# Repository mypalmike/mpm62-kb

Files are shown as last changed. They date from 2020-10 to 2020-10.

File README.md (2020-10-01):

# mpm62-kb
Schematics etc for split 62-key 60% keyboard.

Left side uses an arduino pro micro with left-side exit. Right side uses expander. Simple 4-pin connector carries i2c.

## Status

Currently in early stages.

* 2020-09-04 - Probably not final, but first potentially viable schematic.
* 2020-09-06 - Right-side (more complex) PCB routing complete.
* 2020-09-30 - (branch) Both sides updated for throughhole solder and expander to simplify wiring.

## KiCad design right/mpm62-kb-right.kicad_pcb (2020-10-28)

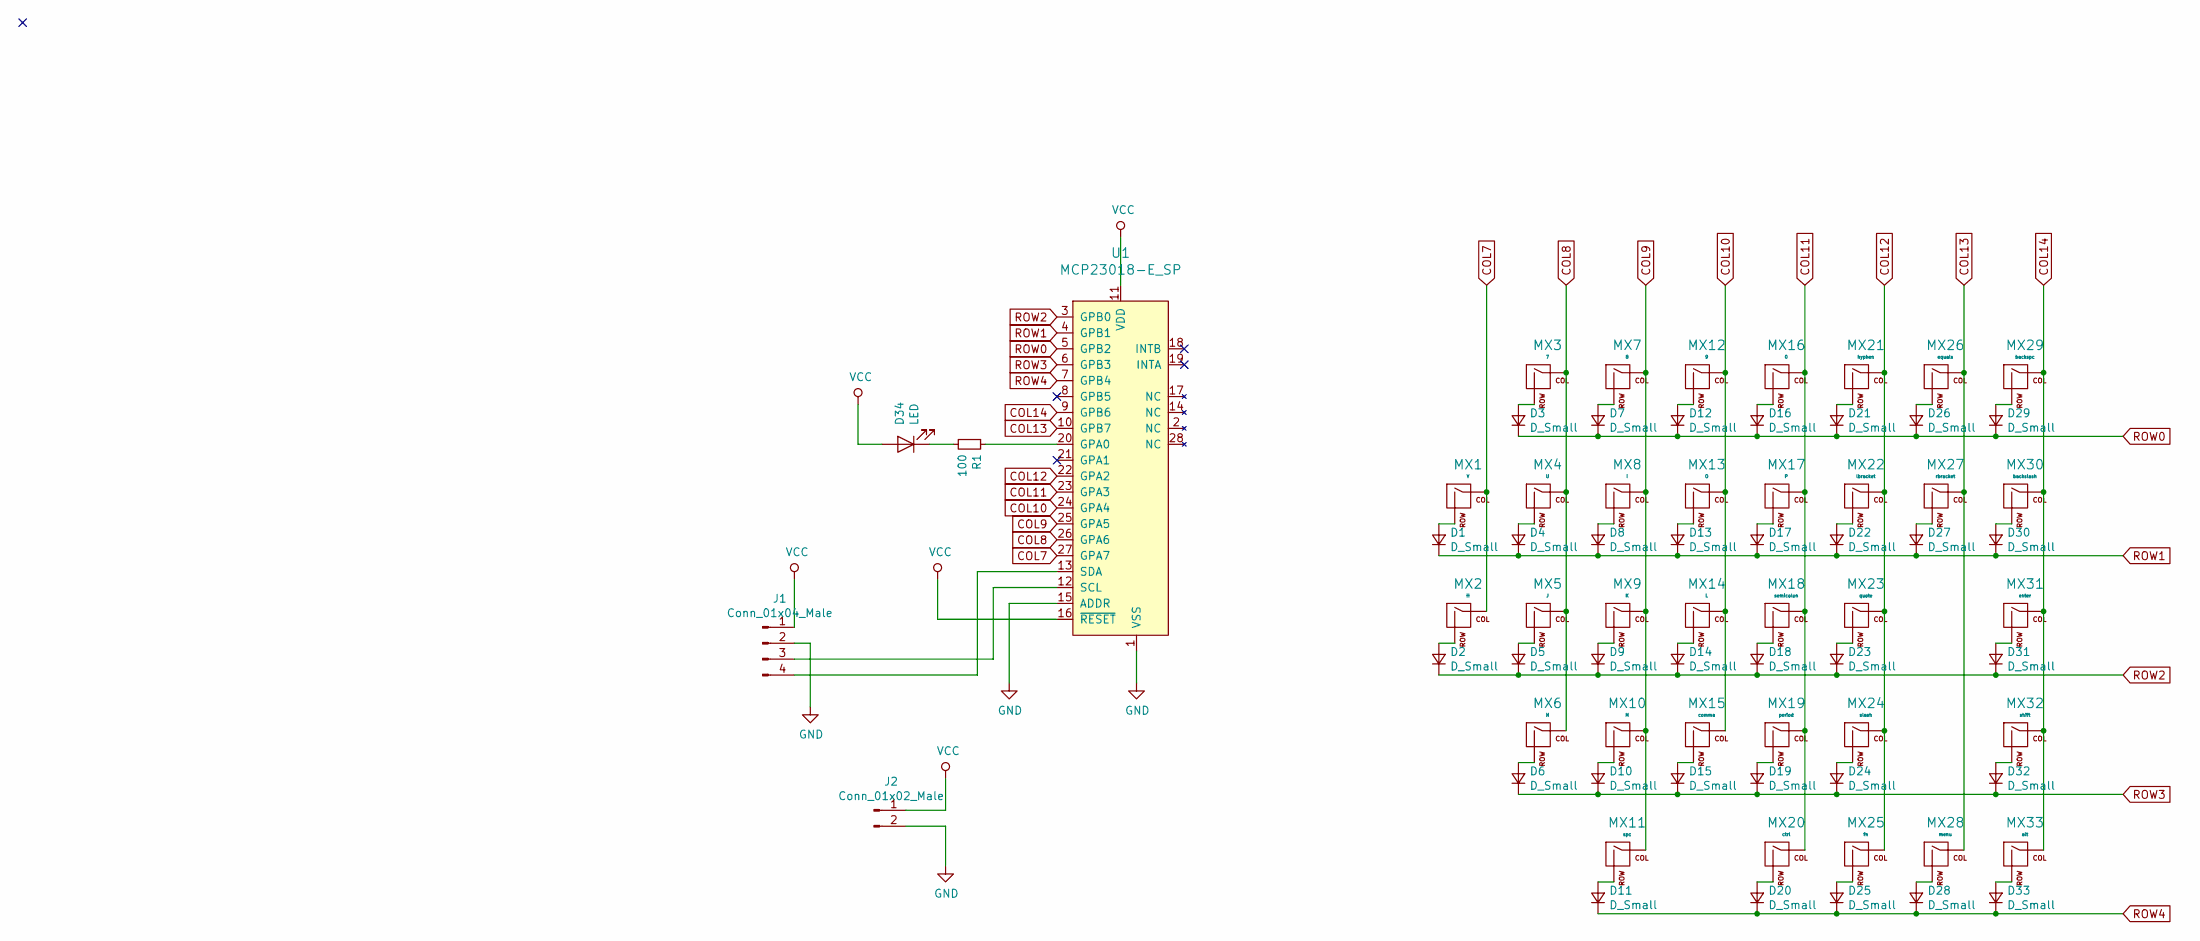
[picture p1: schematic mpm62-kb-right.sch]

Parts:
D1, D2, D3, D4, D5, D6, D7, D8, D9, D10, D11, D12, D13, D14, D15, D16, D17, D18, D19, D20, D21, D22, D23, D24, D25, D26, D27, D28, D29, D30, D31, D32, D33: D_Small; D_DO-35_SOD27_P7.62mm_Horizontal
D34: LED; LED_D3.0mm
J1: Conn_01x04_Male; PinHeader_1x04_P2.54mm_Vertical
J2: Conn_01x02_Male; PinHeader_1x02_P2.54mm_Vertical
MX1: Y; MX-1U-NoLED
MX2: H; MX-1U-NoLED
MX3: 7; MX-1U-NoLED
MX4: U; MX-1U-NoLED
MX5: J; MX-1U-NoLED
MX6: N; MX-1U-NoLED
MX7: 8; MX-1U-NoLED
MX8: I; MX-1U-NoLED
MX9: K; MX-1U-NoLED
MX10: M; MX-1U-NoLED
MX11: spc; MX-3U-ReversedStabilizers-NoLED
MX12: 9; MX-1U-NoLED
MX13: O; MX-1U-NoLED
MX14: L; MX-1U-NoLED
MX15: comma; MX-1U-NoLED
MX16: 0; MX-1U-NoLED
MX17: P; MX-1U-NoLED
MX18: semicolon; MX-1U-NoLED
MX19: period; MX-1U-NoLED
MX20: ctrl; MX-1.25U-NoLED
MX21: hyphen; MX-1U-NoLED
MX22: lbracket; MX-1U-NoLED
MX23: quote; MX-1U-NoLED
MX24: slash; MX-1U-NoLED
MX25: fn; MX-1.25U-NoLED
MX26: equals; MX-1U-NoLED
MX27: rbracket; MX-1U-NoLED
MX28: menu; MX-1.25U-NoLED
MX29: backspc; MX-2U-NoLED
MX30: backslash; MX-1.5U-NoLED
MX31: enter; MX-2.25U-NoLED
MX32: shift; MX-2.75U-NoLED
MX33: alt; MX-1.25U-NoLED
R1: 100; R_Axial_DIN0207_L6.3mm_D2.5mm_P7.62mm_Horizontal
U1: MCP23018-E_SP; DIP-28_W7.62mm; MPN MCP23018-E/SP; Digi-Key_PN MCP23018-E/SP-ND

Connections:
COL7: MX1.1 (COL), MX2.1 (COL), U1.27 (GPA7)
COL8: MX3.1 (COL), MX4.1 (COL), MX5.1 (COL), MX6.1 (COL), U1.26 (GPA6)
COL9: MX7.1 (COL), MX8.1 (COL), MX9.1 (COL), MX10.1 (COL), MX11.1 (COL), U1.25 (GPA5)
COL10: MX12.1 (COL), MX13.1 (COL), MX14.1 (COL), MX15.1 (COL), U1.24 (GPA4)
COL11: MX16.1 (COL), MX17.1 (COL), MX18.1 (COL), MX19.1 (COL), MX20.1 (COL), U1.23 (GPA3)
COL12: MX21.1 (COL), MX22.1 (COL), MX23.1 (COL), MX24.1 (COL), MX25.1 (COL), U1.22 (GPA2)
COL13: MX26.1 (COL), MX27.1 (COL), MX28.1 (COL), U1.10 (GPB7)
COL14: MX29.1 (COL), MX30.1 (COL), MX31.1 (COL), MX32.1 (COL), MX33.1 (COL), U1.9 (GPB6)
GND: J1.2, J2.2, U1.1 (VSS), U1.15 (ADDR)
unnamed: D1.2 (A), MX1.2 (ROW)
unnamed: D2.2 (A), MX2.2 (ROW)
unnamed: D3.2 (A), MX3.2 (ROW)
unnamed: D4.2 (A), MX4.2 (ROW)
unnamed: D5.2 (A), MX5.2 (ROW)
unnamed: D6.2 (A), MX6.2 (ROW)
unnamed: D7.2 (A), MX7.2 (ROW)
unnamed: D8.2 (A), MX8.2 (ROW)
unnamed: D9.2 (A), MX9.2 (ROW)
unnamed: D10.2 (A), MX10.2 (ROW)
unnamed: D11.2 (A), MX11.2 (ROW)
unnamed: D12.2 (A), MX12.2 (ROW)
unnamed: D13.2 (A), MX13.2 (ROW)
unnamed: D14.2 (A), MX14.2 (ROW)
unnamed: D15.2 (A), MX15.2 (ROW)
unnamed: D16.2 (A), MX16.2 (ROW)
unnamed: D17.2 (A), MX17.2 (ROW)
unnamed: D18.2 (A), MX18.2 (ROW)
unnamed: D19.2 (A), MX19.2 (ROW)
unnamed: D20.2 (A), MX20.2 (ROW)
unnamed: D21.2 (A), MX21.2 (ROW)
unnamed: D22.2 (A), MX22.2 (ROW)
unnamed: D23.2 (A), MX23.2 (ROW)
unnamed: D24.2 (A), MX24.2 (ROW)
unnamed: D25.2 (A), MX25.2 (ROW)
unnamed: D26.2 (A), MX26.2 (ROW)
unnamed: D27.2 (A), MX27.2 (ROW)
unnamed: D28.2 (A), MX28.2 (ROW)
unnamed: D29.2 (A), MX29.2 (ROW)
unnamed: D30.2 (A), MX30.2 (ROW)
unnamed: D31.2 (A), MX31.2 (ROW)
unnamed: D32.2 (A), MX32.2 (ROW)
unnamed: D33.2 (A), MX33.2 (ROW)
unnamed: D34.1 (K), R1.2
unnamed: J1.3, U1.12 (SCL)
unnamed: J1.4, U1.13 (SDA)
unnamed: R1.1, U1.20 (GPA0)
ROW0: D3.1 (K), D7.1 (K), D12.1 (K), D16.1 (K), D21.1 (K), D26.1 (K), D29.1 (K), U1.5 (GPB2)
ROW1: D1.1 (K), D4.1 (K), D8.1 (K), D13.1 (K), D17.1 (K), D22.1 (K), D27.1 (K), D30.1 (K), U1.4 (GPB1)
ROW2: D2.1 (K), D5.1 (K), D9.1 (K), D14.1 (K), D18.1 (K), D23.1 (K), D31.1 (K), U1.3 (GPB0)
ROW3: D6.1 (K), D10.1 (K), D15.1 (K), D19.1 (K), D24.1 (K), D32.1 (K), U1.6 (GPB3)
ROW4: D11.1 (K), D20.1 (K), D25.1 (K), D28.1 (K), D33.1 (K), U1.7 (GPB4)
VCC: D34.2 (A), J1.1, J2.1, U1.11 (VDD), U1.16 (~RESET)

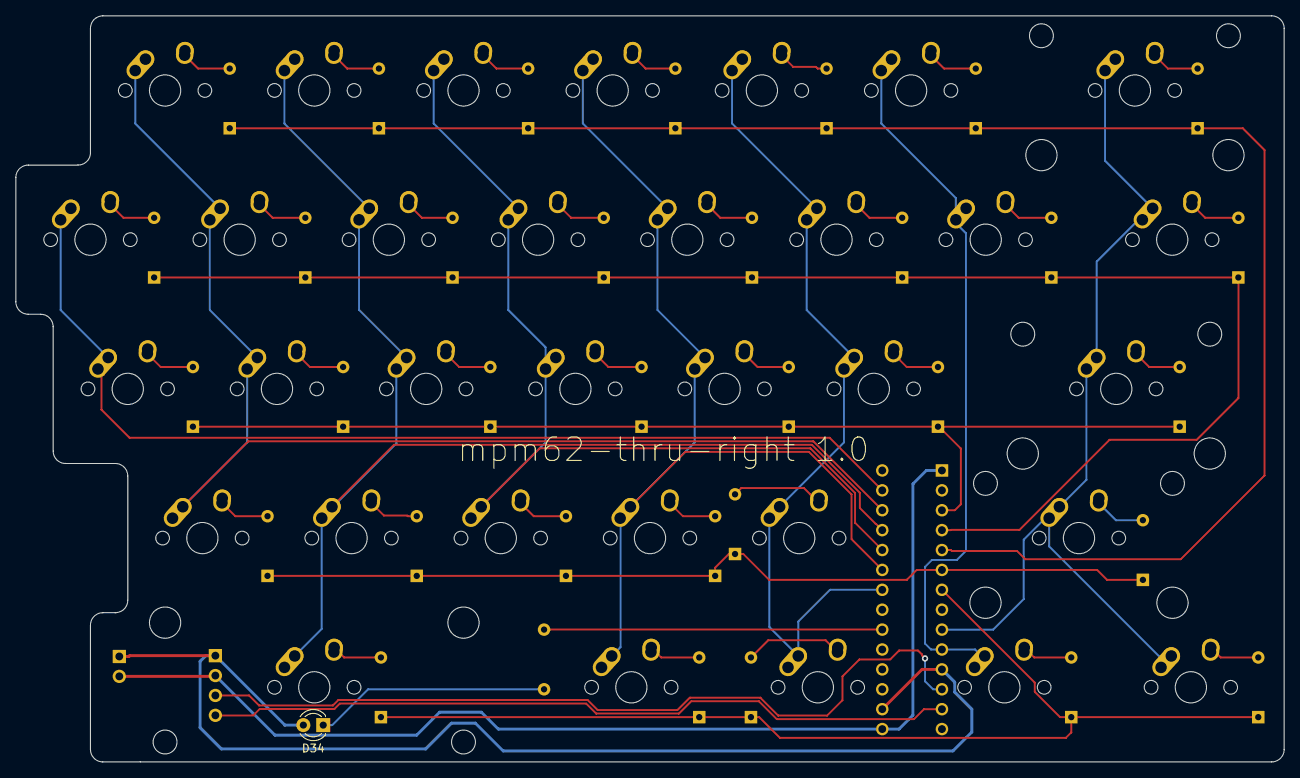
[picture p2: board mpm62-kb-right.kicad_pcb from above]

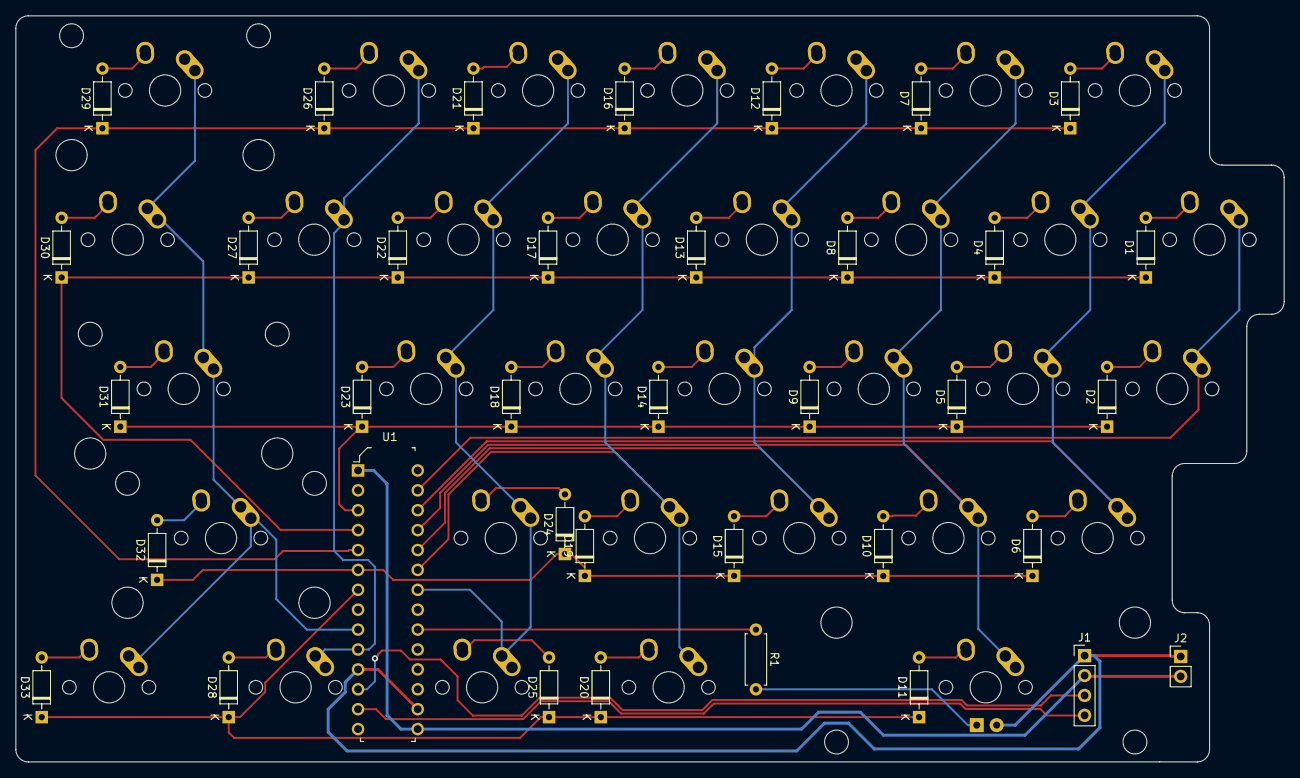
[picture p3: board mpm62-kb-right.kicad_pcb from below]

Board: 2 copper layers, 161.9 x 95.2 mm, 71 parts (37 on the bottom side), 52 nets.

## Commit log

2020-09-01 Initial empty project
    [mpm62-kb-left.kicad_pcb, mpm62-kb-left.sch]
2020-09-01 left schematic first pass
    [mpm62-kb-left.sch]
2020-09-01 Initial project for right
    [mpm62-kb-right.kicad_pcb, mpm62-kb-right.sch]
2020-09-01 Add cache schematic lib for left
2020-09-01 Right MCU and switch layout.
    [mpm62-kb-right.sch]
2020-09-04 complete schematics for both left and right
    [mpm62-kb-left.sch, mpm62-kb-right.sch]
2020-09-06 Add usb connector. Cleaned up crystal in schematic.
    [mpm62-kb-right.sch]
2020-09-06 Annotated components
    [mpm62-kb-right.sch]
2020-09-06 Assigned footprints
    [mpm62-kb-right.sch]
2020-09-06 Right pcb almost done.
    [mpm62-kb-right.kicad_pcb]
2020-09-07 Right pcb complete
    [mpm62-kb-right.kicad_pcb]
2020-09-07 Minor pcb cleanup near crystal.
    [mpm62-kb-right.kicad_pcb]
2020-09-30 Schematic and pre-routed right-side based on mcp23018
    [mpm62-kb-right.kicad_pcb, mpm62-kb-right.sch]
2020-09-30 Fix resistor footprint, clean up layout.
    [mpm62-kb-right.kicad_pcb, mpm62-kb-right.sch]
2020-09-30 Finished right side routing, some simplification, ground fill.
    [mpm62-kb-right.kicad_pcb, mpm62-kb-right.sch]
2020-09-30 Add version text to front silk layer
    [mpm62-kb-right.kicad_pcb]
2020-10-01 left side pcb components in place, not routed.
    [mpm62-kb-left.kicad_pcb, mpm62-kb-left.sch]
2020-10-01 Left side routed.
    [mpm62-kb-left.kicad_pcb, mpm62-kb-left.sch]
2020-10-01 left side ground filled and silk layer label
    [mpm62-kb-left.kicad_pcb]
2020-10-01 Generated gerbers.
    [mpm62-kb-left-B_Cu.gbl, mpm62-kb-left-B_Mask.gbs, mpm62-kb-left-B_SilkS.gbo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]
2020-10-01 Fix some small components in path of stabilizers.
    [mpm62-kb-right.kicad_pcb]
2020-10-01 Generated right side gerber files.
    [mpm62-kb-right-B_Cu.gbl, mpm62-kb-right-B_Mask.gbs, mpm62-kb-right-B_SilkS.gbo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]
2020-10-01 Minor config.
    [mpm62-kb-right.kicad_pcb]
2020-10-28 Fix issues with left side: 1. SCL and SDA are swapped in the library file from github/ProMicroKiCad. Current fix is to swap the wires and mark the schematic to show which is which. Ultimately it woul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
    [mpm62-kb-left.kicad_pcb, mpm62-kb-left.sch]
2020-10-28 Fix issues on right side: 1. Remove reset switch and connect reset directly to vcc - switch was not useful and added complexity. 2. Inverted spacebar stabilizer holes (previous commit did not mention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
    [mpm62-kb-right.kicad_pcb, mpm62-kb-right.sch]
